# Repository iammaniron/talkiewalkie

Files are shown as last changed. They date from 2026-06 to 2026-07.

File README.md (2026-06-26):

# TalkieWalkie

A portable 2.4 GHz digital walkie-talkie — designed with KiCad. TalkieWalkie is a compact, battery-powered two-way radio that transmits and receives voice over the 2.4 GHz ISM band using the Nordic nRF24L01 transceiver.

## Features

- **2.4 GHz Wireless Communication** — nRF24L01+ module for digital voice/data transmission
- **Full-Duplex Audio** — Nuvoton NAU8325 audio codec with dual-channel MEMS microphones
- **OLED Display** — 0.91" 128×32 I²C OLED for status, settings, and feedback
- **MicroSD Storage** — Onboard MicroSD slot for audio recording, firmware updates, or configuration
- **RGB LED Indicator** — Multi-color status LED for TX/RX/power indication
- **Battery Powered** — Single 18650 Li-Ion cell for portable operation
- **Compact Board** — 1.6 mm standard thickness, 2-layer PCB

## Hardware

### Bill of Materials

| Reference | Component | Description |
|---|---|---|
| U1 | GLYPH-S3 | Main MCU module (28-pin castellated) |
| U2 | nRF24L01 Breakout | 2.4 GHz RF transceiver module |
| U3 | GMOD-NAU8325 | Audio codec module (Nuvoton NAU8325) |
| U4 | Gsense-2CH-MIC | Dual-channel MEMS microphone module |
| U5 | ER-OLEDM0.91-1x-I2C | 0.91" 128×32 OLED display |
| U6 | GMOD-MICRO SD CARD | MicroSD card slot module |
| BT1 | BK-18650-PC2 | 18650 Li-Ion battery holder |
| D1 | LED_KRGB | RGB LED (common cathode) |
| SW1 | SW_Push | Tactile push button (Omron B3F-315x angled) |
| J1 | Conn_01x05_Pin | 5-pin programming/debug header (1.27 mm pitch) |
| J2,J3 | Conn_01x02_Pin | 2-pin headers (expansion/GPIO) |

### Board Specifications

| Parameter | Value |
|---|---|
| Layers | 2 |
| Thickness | 1.6 mm |
| Min track width | 0.2 mm |
| Min clearance | 0.2 mm |
| Via diameter | 0.6 mm |
| Via drill | 0.3 mm |
| Power rails | +3.3 V, GND |
| Battery | 1× 18650 Li-Ion (3.7 V nominal) |

## System Architecture

```
┌─────────────────────────────────────────────────────┐
│                    TalkieWalkie                      │
│                                                      │
│  ┌──────────┐   ┌──────────┐   ┌───────────────┐   │
│  │ 18650    │──▶│ GLYPH-S3 │◀──│ OLED 0.91"    │   │
│  │ Battery  │   │  (MCU)   │   │ (I²C Display) │   │
│  └──────────┘   └─┬──┬──┬──┘   └───────────────┘   │
│                   │  │  │                           │
│         ┌─────────┘  │  └──────────┐               │
│         ▼            ▼             ▼               │
│  ┌───────────┐ ┌──────────┐ ┌───────────┐         │
│  │ nRF24L01  │ │ NAU8325  │ │ MicroSD   │         │
│  │ 2.4GHz RF │ │ Audio    │ │ Storage   │         │
│  └───────────┘ │ Codec    │ └───────────┘         │
│                └────┬─────┘                        │
│                     │                              │
│                ┌────▼─────┐                        │
│                │ Dual-MIC │                        │
│                │ Gsense   │                        │
│                └──────────┘                        │
│                                                      │
│  ┌──────────┐                      ┌────────────┐  │
│  │ RGB LED  │                      │ Debug/Exp  │  │
│  │ (Status) │                      │ Headers    │  │
│  └──────────┘                      └────────────┘  │
└─────────────────────────────────────────────────────┘
```

### Signal Flow

1. **TX Path**: Dual MEMS mics → NAU8325 ADC → GLYPH-S3 (encode/compress) → nRF24L01 (GFSK TX)
2. **RX Path**: nRF24L01 (GFSK RX) → GLYPH-S3 (decode/decompress) → NAU8325 DAC → speaker/headphone out
3. **Storage**: Audio streams can be recorded to MicroSD for later playback or logging
4. **UI**: OLED shows channel, battery level, signal strength; RGB LED indicates TX/RX/standby

## How It Works

The GLYPH-S3 MCU orchestrates all peripherals over SPI and I²C buses. During transmission, the NAU8325 captures and digitizes audio from the dual MEMS microphones. The MCU encodes the PCM stream (potentially with compression) and packets it out over the nRF24L01 in the 2.4 GHz band. On the receive side, the nRF24L01 demodulates incoming packets, the MCU decodes the stream, and the NAU8325 drives an external speaker.

The OLED provides a real-time interface showing channel selection, battery gauge, and link status. The RGB LED gives at-a-glance feedback — red for TX, green for RX, blue for idle/standby.

### Protocol Considerations

- nRF24L01 operates at up to 2 Mbps over-the-air data rate
- Enhanced ShockBurst™ for automatic packet handling and acknowledgements
- 125 RF channels (2.400 – 2.525 GHz), 1 MHz spacing
- Payload up to 32 bytes per packet — requires audio stream segmentation

## Project Status

- [x] Schematic design
- [x] Footprint assignment
- [x] Component placement
- [ ] PCB routing (in progress)
- [ ] Design rule check (DRC)
- [ ] Fabrication & assembly
- [ ] Firmware development

## Repository Structure

```
talkiewalkie/
├── walkietalkie.kicad_pro   # KiCad project file
├── walkietalkie.kicad_sch   # Schematic (top-level sheet)
├── walkietalkie.kicad_pcb   # PCB layout
├── walkietalkie.kicad_prl   # Local project settings
├── README.md                # This file
└── .history/                # Schematic revision history
```

## Tools

- **KiCad** — PCB design (schematic capture + board layout)
- Designed by **PCB CUPID**

## License

Hardware design files are provided as-is for reference and educational purposes.

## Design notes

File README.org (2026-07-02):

#+TITLE: teleVox — A DIY Walkie Talkie
#+AUTHOR: ManIron
#+DATE: July 2026

* The Story

It started with a YouTube video.

A friend and fellow creator was building a walkie talkie using Glyph
boards. It worked — technically. But it was held together on a
breadboard, and anyone who has worked with breadboards knows the
struggle: loose connections, noise, wires everywhere, and the constant
question of "why did it just stop working?"

That video planted a seed.

I had been wanting to learn PCB design for a while, and this felt like
the perfect excuse. Instead of designing a full walkie talkie board
from scratch — which would be insane for a first project — I could
design a *carrier board*. A single board that brings the Glyph, the
audio codec, the amplifier, the microphone, the battery management,
and all the supporting circuitry together into one clean package.

It seemed simple enough. A perfect beginner project. A great piece of
content. Maybe a week of work.

I was wrong. And I'm glad I was.

What followed was one of the most intense, frustrating, and rewarding
learning experiences I have ever had. I learned about schematics and
how to read datasheets. I learned about component placement and why
"just connect the pins" is not a routing strategy. I learned about
power distribution, ground planes, decoupling capacitors, and why your
microcontroller resets when the transmitter keys up if you get it
wrong. I learned about buses, differential pairs, ERC and DRC errors,
footprint libraries, design rules, manufacturing constraints, and a
hundred other things I didn't even know existed two weeks earlier.

There were moments when I felt completely stuck. Moments where I
thought I had finished, only to realize I needed to tear something up
and start over. I learned very quickly that a good schematic does not
automatically become a good PCB. The schematic is the vision; the
layout is where reality pushes back.

Thankfully, I was not alone. I had mentors who patiently guided me
through the process. Every time I thought I had figured something out,
they would point out a better way, explain the reasoning behind it,
and push me to think like an engineer, not just a hobbyist following a
tutorial. They reviewed my designs, answered my questions at odd
hours, and made sure I was heading in the right direction.

Today, the board has officially been sent for manufacturing. Seeing
the final design and clicking that "Order" button gave me goosebumps.
Whether it works perfectly on the first try or needs revisions, I have
already learned more than I ever expected.

This is not just a PCB. It is proof that you can start from zero and
build something real.

* What is teleVox?

teleVox is a DIY walkie talkie built around the [[https://www.instagram.com/reezen.xyz/][Glyph]] ecosystem. It is
designed as a carrier board — a custom PCB that integrates off-the-shelf
modules into a single, compact, battery-powered handheld device.

The goal is simple: a walkie talkie that actually works reliably, with
a proper PCB instead of a breadboard, enclosed in a 3D printed shell,
powered by a rechargeable battery.

* How It Works

The system is built around these core blocks:

- *Glyph C3* — the brain. An ESP32-C3 based development board that
  handles the digital audio processing and wireless communication.
- *Audio Codec (ES8388)* — converts analog audio from the microphone
  to digital (ADC) and digital audio back to analog (DAC) for the
  speaker.
- *Microphone* — a MEMS microphone with on-board amplifier for clear
  voice capture.
- *Audio Amplifier (MAX98357)* — a Class-D amplifier that drives the
  speaker with enough volume to be heard clearly.
- *Battery Management* — a TP4056 based charging circuit with
  protection, allowing the device to run on a single 18650 Li-Ion cell
  and charge via USB-C.
- *Power Regulation* — buck and boost converters to provide stable
  3.3V and 5V rails from the battery.
- *User Interface* — physical buttons for PTT (Push-To-Talk), volume,
  and channel selection, plus status LEDs.
- *3D Printed Enclosure* — a custom shell that houses everything in a
  handheld form factor.

* The Design

The PCB was designed in [[https://www.kicad.org/][KiCad]], an open-source EDA tool. The design
went through several iterations:

1. *Schematic Capture* — drawing up the circuit, selecting components,
   checking pinouts against datasheets, and running electrical rules
   checks (ERC).
2. *Component Placement* — arranging everything on the board for
   minimal trace lengths, clean power delivery, and good thermal
   performance.
3. *Routing* — connecting all the nets. This was the hardest part.
   Two-layer board, mixed-signal (audio and digital), careful ground
   plane management, keeping audio traces away from switching noise.
4. *Design Rule Checking (DRC)* — making sure the board meets
   manufacturing constraints: trace width, clearance, via size,
   silkscreen readability.
5. *Gerber Generation* — exporting the manufacturing files and
   sending them off to the fab.

The board is a two-layer design with a solid ground plane on the
bottom layer, star-ground topology for the audio section, and
dedicated power pours for the high-current paths.

* The Enclosure

The teleVox enclosure is a 3D printed shell designed in Fusion 360:

- Two-part clamshell design with screw bosses
- Cutouts for the speaker grille, microphone port, buttons, and USB-C
- Snap-fit battery compartment for easy cell swapping
- Designed for FDM printing with minimal supports

* Repository Structure

- =walkietalkie.kicad_pro= — KiCad project file
- =walkietalkie.kicad_sch= — Schematic
- =walkietalkie.kicad_pcb= — PCB layout
- =walkietalkie.kicad_prl= — Netlist / project locals
- =the final gerber/= — Manufacturing files sent to the fab
- =teleVox.glb= — 3D model of the device
- =teleVox.step= — STEP file for the enclosure / mechanical integration
- =.step= — Additional mechanical data

* Acknowledgments

This project would not have been possible without the people who took
the time to teach, review, and guide. You know who you are — thank you
for making me think like an engineer.

Also huge thanks to the KiCad team for building incredible open-source
tools, and to the ESP32 and audio communities for the libraries and
reference designs that made this possible.

* What's Next?

The boards are at the fab. When they arrive:

- Assembly and soldering
- Bring-up and testing
- Firmware development
- Enclosure printing and fitting
- Field testing

If the first revision has issues — that's okay. That's part of the
process. Each revision will be better than the last.

* License

This project is open-source hardware. Feel free to learn from it,
modify it, and build your own.

#+begin_quote
Built with curiosity, caffeine, and KiCad.
#+end_quote

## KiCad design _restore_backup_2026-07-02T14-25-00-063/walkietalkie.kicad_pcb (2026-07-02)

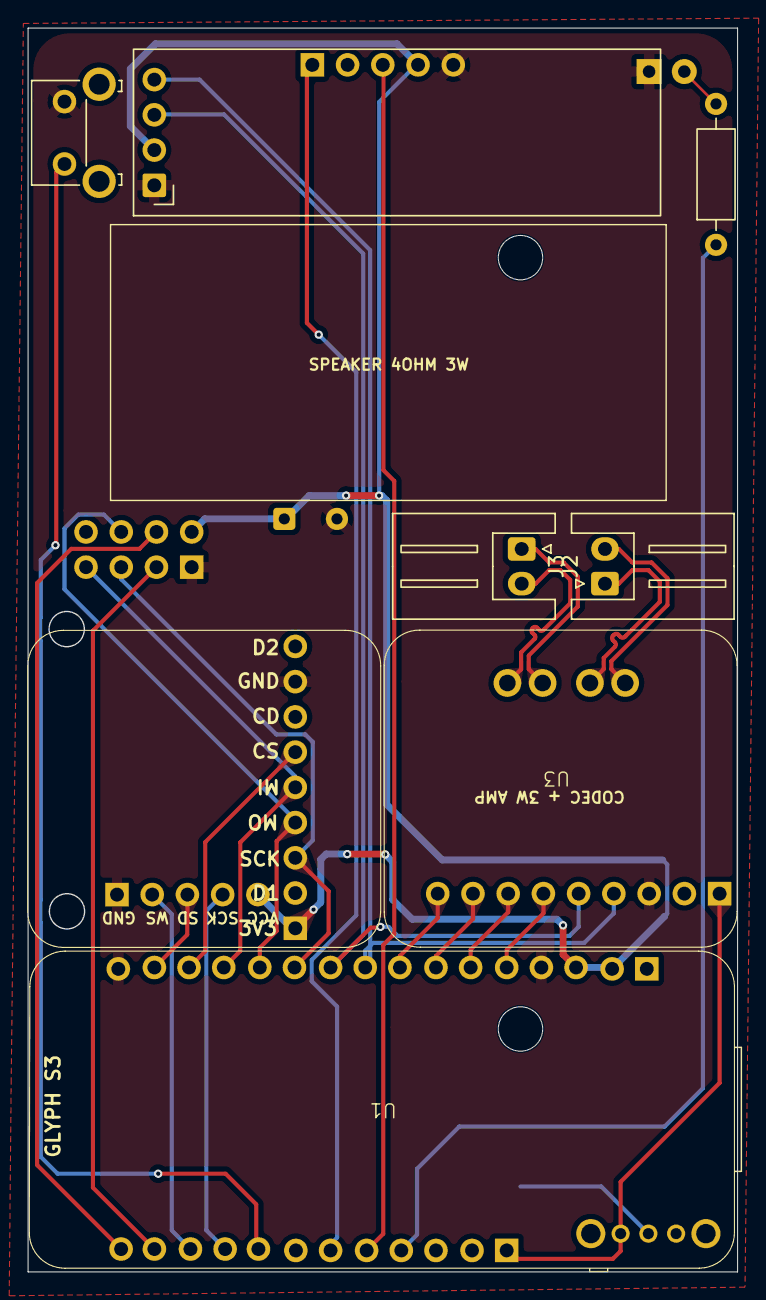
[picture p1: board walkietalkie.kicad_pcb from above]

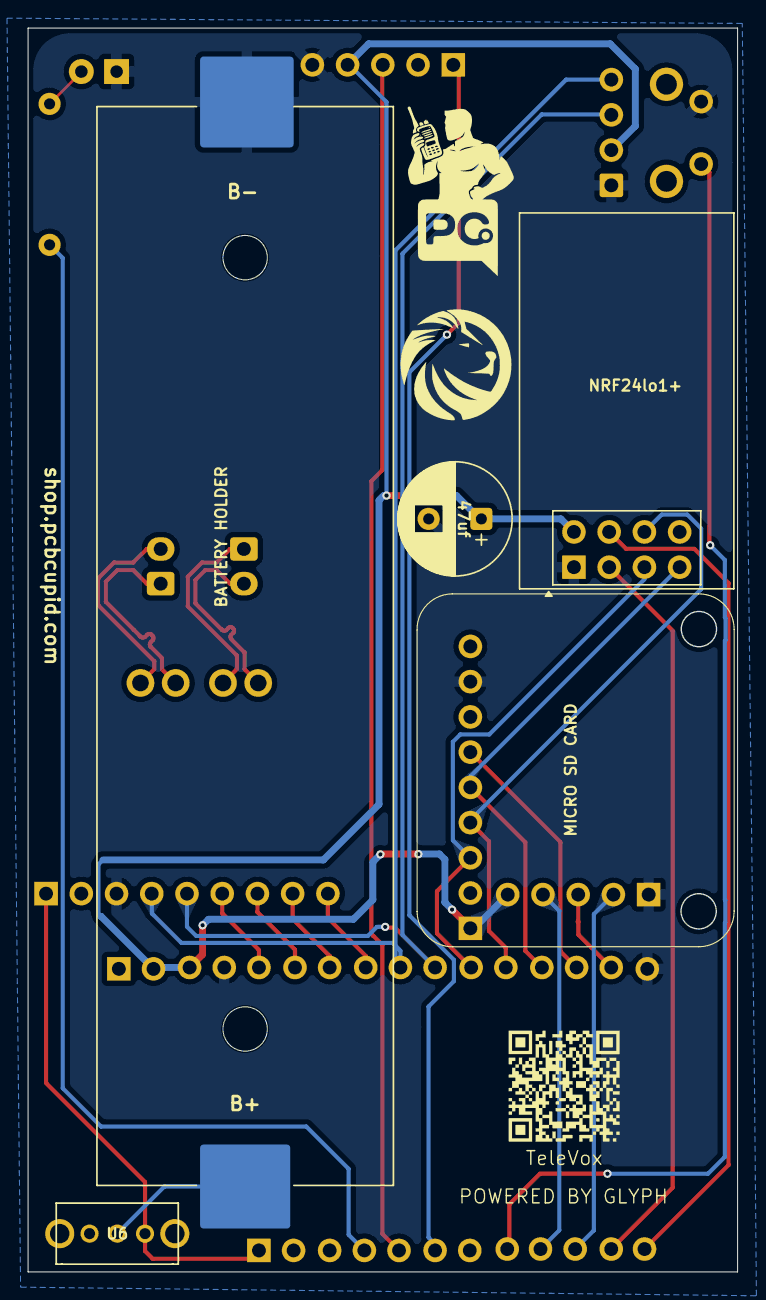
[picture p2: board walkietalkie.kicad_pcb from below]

Board: 2 copper layers, 51.2 x 89.7 mm, 15 parts (7 on the bottom side), 29 nets.

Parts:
BT1: BK-18650-PC2; BatteryHolder_1042_1x18650
C1: C_Polarized; CP_Radial_D8.0mm_P3.80mm
D1: LED; LED_D5.0mm
J1: Conn_01x05_Pin; PinHeader_1x05_P2.54mm_Vertical
J2, J3: Conn_01x02_Pin; JST_XH_S2B-XH-A_1x02_P2.50mm_Horizontal
R1: R; R_Axial_DIN0207_L6.3mm_D2.5mm_P10.16mm_Horizontal
SW1: PTT; SW_SPST_Omron_B3F-315x_Angled
U1: glyph-s3
U2: NRF24L01_Breakout; nRF24L01_Breakout
U3: gmod-audio_codec
U4: CH2 mic
U5: gmod-micro_sd
U6: SK12D07VG4
U7: ER_OLEDM0.91_1x-I2C

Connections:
+3V3: C1.1, J1.4, U1.14 (3V3), U1.15 (3V3), U2.2 (VCC), U4.5 (3.3V), U5.1 (3.3V), U7.2 (VCC)
/BAT: U1.12 (BAT), U3.1 (5V), U6.2
/BCLK: U1.18 (D14), U3.7 (BCK)
/CE: U1.2 (SDA), U2.3 (CE)
/CSN: U1.1 (SCL), U2.4 (~CSN)
/ENC_A: J1.1, U1.7 (A8)
/ENC_B: J1.2, U1.6 (A7)
/ENC_SW: J1.3, U1.8 (A9)
/LED: R1.1, U1.9 (A10)
/LRCK: U1.20 (D16), U3.9 (LRCK)
/MI: U1.25 (MI), U2.7 (MISO), U5.5 (MI)
/MIC_SD: U1.27 (TX), U4.3 (SD)
/MO: U1.24 (MO), U2.6 (MOSI), U5.4 (MO)
/MSCK: U1.4 (A2), U4.4 (SCK)
/NAU_DAT: U1.19 (D15), U3.8 (DAT)
/NAU_MCLK: U1.17 (D13), U3.6 (MCLK)
/PTT: SW1.1, U1.5 (A6)
/SCK: U1.23 (SCK), U2.5 (SCK), U5.3 (SCK)
/SCL: U1.22 (D18), U3.5 (SCL), U7.3 (SCL)
/SDA: U1.21 (D17), U3.4 (SDA), U7.4 (SDA)
/WS: U1.3 (A1), U4.2 (WS)
/_LN: J3.1, U3.11 (LN)
/_LP: J3.2, U3.10 (LP)
/_RN: J2.1 (Pin_2), U3.12 (RN)
/_RP: J2.2 (Pin_1), U3.13 (RP)
GND: BT1.2, C1.2, D1.1 (K), J1.5, SW1.2, U1.16 (GND), U1.28 (GND), U2.1 (GND), U3.3 (GND), U4.1 (GND), U5.8 (GND), U7.1 (GND)
unnamed: BT1.1, U6.COM
unnamed: D1.2 (A), R1.2
unnamed: U1.26 (RX), U5.6 (CS)

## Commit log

2026-06-24 added rough schematics
    [walkietalkie.kicad_pcb, walkietalkie.kicad_sch]
2026-06-25 schematics done
    [walkietalkie.kicad_sch]
2026-06-25 schematics is done
2026-06-25 assigning footprints done
    [walkietalkie.kicad_sch]
2026-06-26 placements of the components are done, routing left
    [walkietalkie.kicad_pcb, walkietalkie.kicad_sch]
2026-06-26 docs: add project README with BOM and board specs
2026-06-26 docs: add system architecture, signal flow, and how-it-works section
2026-06-30 feat: finalize component placement, routing remaining
    [walkietalkie.kicad_pcb, walkietalkie.kicad_sch]
2026-06-30 feat: initial routing progress, fix 2ch mic footprint
    [walkietalkie.kicad_pcb, walkietalkie.kicad_sch]
2026-06-30 feat: routing almost done, GND and VCC remaining
    [walkietalkie.kicad_pcb, walkietalkie.kicad_sch]
2026-06-30 fix: resolve schematic problems
    [walkietalkie.kicad_sch]
2026-07-01 routing done
    [walkietalkie.kicad_pcb, walkietalkie.kicad_sch]
2026-07-01 feat: routing done
    [walkietalkie.kicad_pcb]
2026-07-02 feat: silkscreen done, gerber generated, sent to manufacturing
    [walkietalkie-B_Cu.gbr, walkietalkie-B_Mask.gbr, walkietalkie-B_Paste.gbr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]
